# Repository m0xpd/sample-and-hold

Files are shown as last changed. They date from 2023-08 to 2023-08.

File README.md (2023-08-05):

# S&H
A Sample and Hold for Eurorack, based on the LF398

<p width=40%, align="center">

</p>  

This repository describes a simple sample & hold module, developed for electronic synthesisers, in Eurorack format, based on the
[LF398](https://www.ti.com/lit/gpn/lf398-n) device. 

**Functional Description**

S&H is designed to be a simple, "no frills" sample and hold. It just detects a rising edge on the TRIGGER input and samples the 
voltage applied to INPUT at the point of this edge and holds on OUTPUT until the next triggering event. There is a GATE output, 
which is asserted for as long as the TRIGGER signal is high and an internal clock, which generates a trigger stream normalled 
to the edge detection circuits when nothing else is plugged into the TRIGGER input.

**Licensing**

S&H is published under a Creative Commons BY-SA 4.0 [License](https://github.com/m0xpd/encore/blob/main/LICENSE.txt)

**Implementation**

The system is implemented on a single PCB.

The schematic for the system is linked by the graphic below below (click for the full-size schematic):

<p width=100%, align="center">

</p>  

**Specifications**

S&H is 6HP wide and extends 30mm behind the front panel (when a standard Eurorack power header is inserted).

S&H draws <9 mA (typically 5mA) from the +12V supply and <6 mA (typically 3mA) from the -12V supply.

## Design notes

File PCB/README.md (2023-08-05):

# PCB

This folder contains details of the PCB for the S&H module:

The PCB design files are presented in Eagle format.

Below you see a photo of the unpopulated PCB, top and bottom side

<p width=100%, align="center">

</p>  

## BoM and Capacitor Types

A Bill of Materials is available (in the verbose and not very useful style produced by Eagle.

The important things to note are that:
1) the jack sockets and the sample interval potentiometer are mechanically as well as electrically important; they 
control the spacing between the PCB and the front panel. For this reason, [Thonkiconn](https://www.thonk.co.uk/shop/thonkiconn/) sockets
and [alpha 9mm vertical potentiometers](https://www.thonk.co.uk/shop/alpha-9mm-pots-vertical-t18/) are specified.
2) Capacitor Types are as follows:
   C1 & C2 are polarised electrolytics

   C9 was chosen as a box polyester film (for space) - other types (such as multi-layer polyester) are suitable.
   
   C7 must be a low leakage type - I have used a box polyester film reasonably succesfully, but (e.g.) polystyrene would work better.
   
   ALL OTHER CAPS ARE CERAMICS

The populated PBC is seen from the component side in the photo below:

<p width=100%, align="center">

</p>

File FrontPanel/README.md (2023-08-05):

# Front Panel

This folder contains a simple Kicad project to create a front panel for the S&H module.

<p width=100%, align="center">

</p>  

The panel you see above was manufactured by [JLCPCB](https://jlcpcb.com/) (usual disclaimer) directly from the Gerbers generated by my design files.
It is aluminium and I specified black PCB, with white top screen (for the lettering). Other lines and annotation on the front 
are on the front mask layer.

There is a small text area on the bottom screen (the 'back' of the panel), which - importantly - includes a locator for the order 
number. Remember to select 'specify position' for the order number if you order from JLCPCB, otherwise they might place a meaningless 
number right over the front of your nice panel!

[JLCPCB](https://jlcpcb.com/) do a really good job of making the PCBs and (particularly) these front panels BUT there has been a >350% price increase on the panels since 
the last batches they made for me (for the [SubHarmonic Generator](https://github.com/m0xpd/SubHarmonics) and for the [Delay module](https://github.com/m0xpd/encore)). If you want pretty, black panels, I 
guess you have to pay.

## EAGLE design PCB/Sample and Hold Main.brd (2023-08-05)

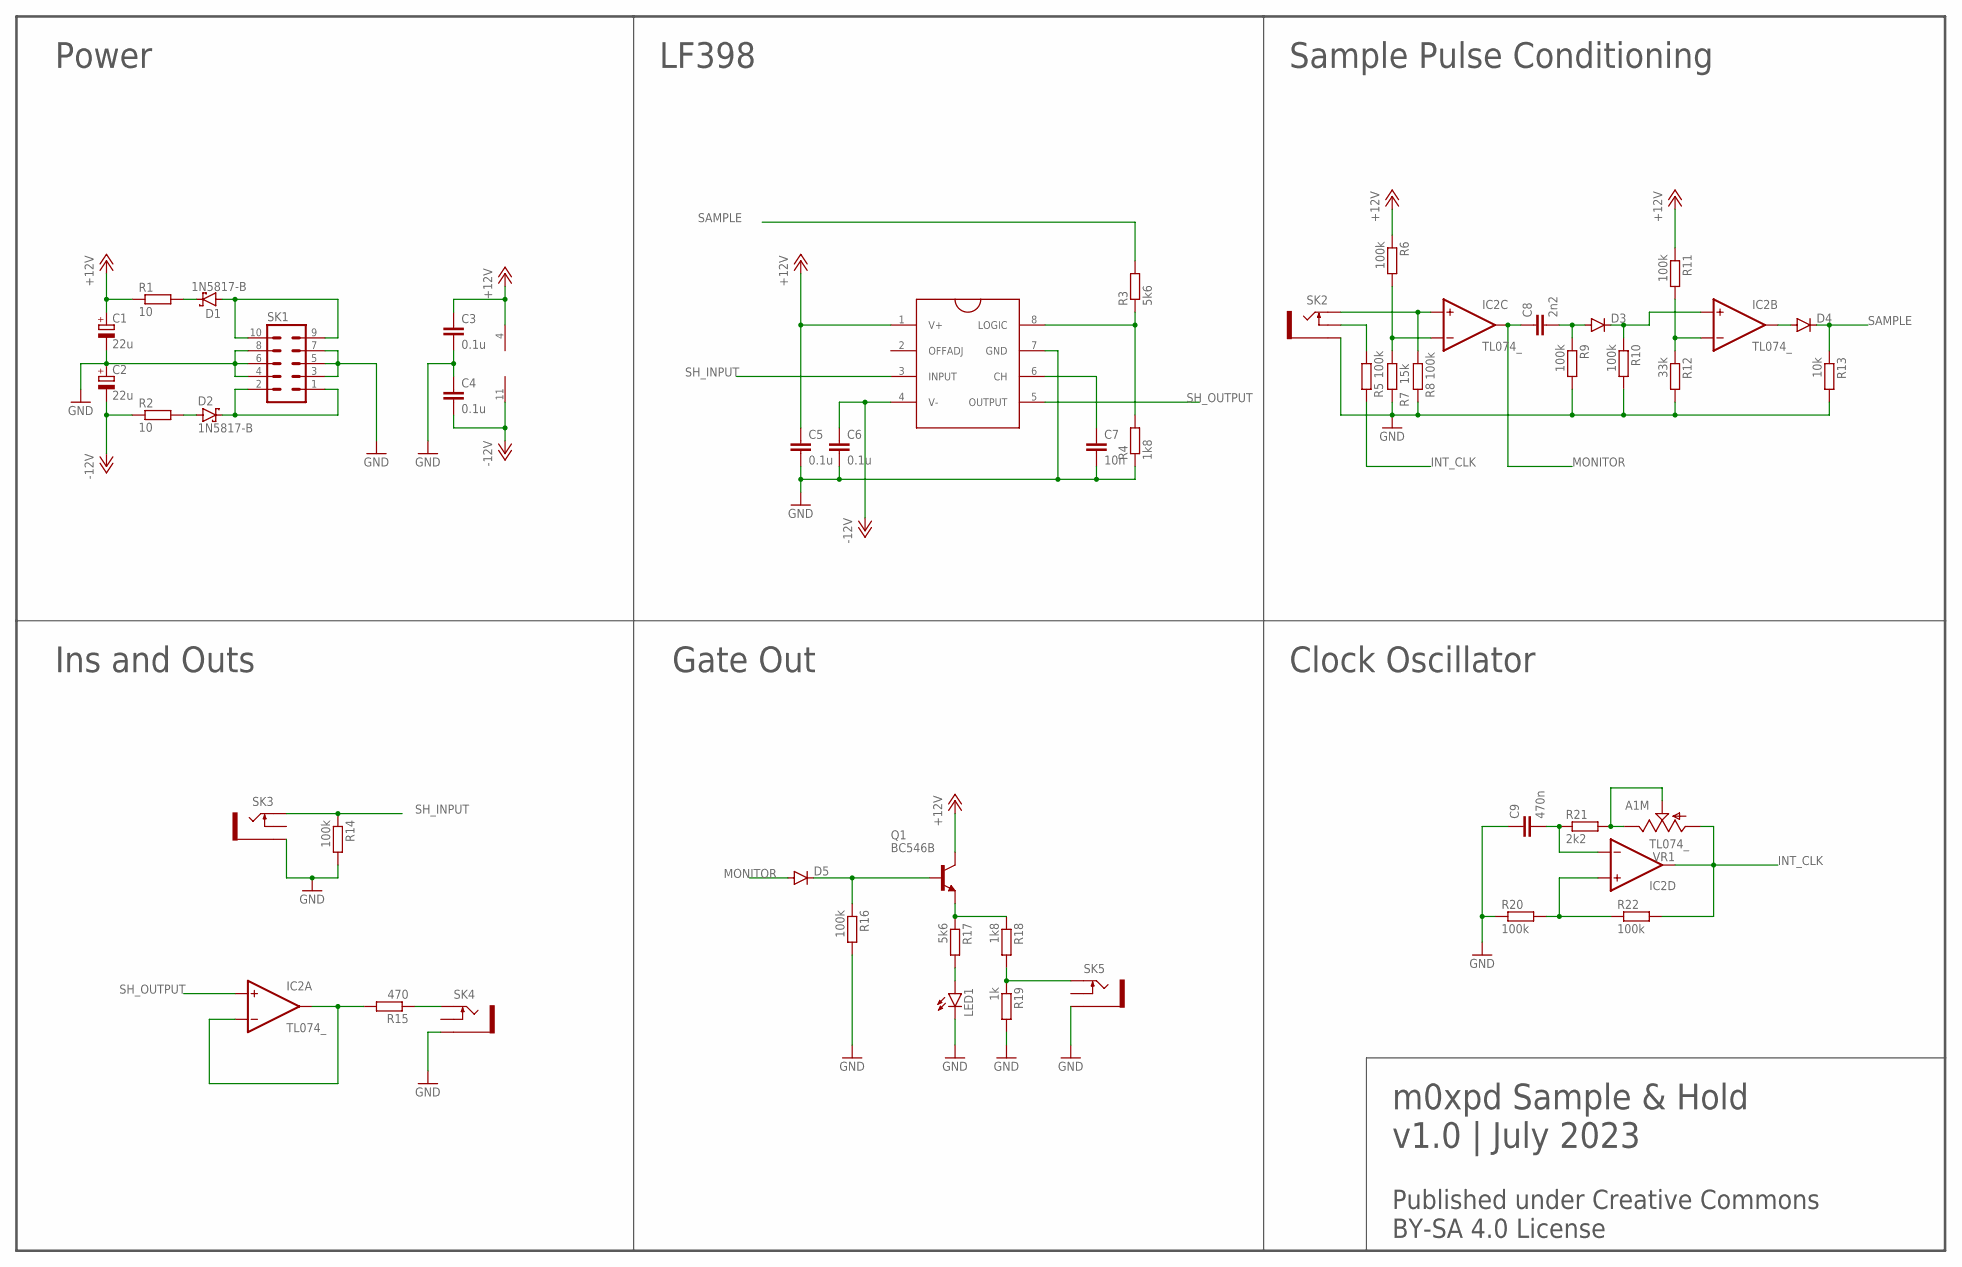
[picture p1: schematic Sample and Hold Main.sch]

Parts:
C1, C2: 22u; E2,5-6
C3, C4, C5, C6: 0.1u; C050-024X044
C7: 10n; C050-025X075
C8: 2n2; C050-024X044
C9: 470n; C050-035X075
D1, D2: 1N5817-B; DO41-7.6
D3, D4, D5: 1N4148DO35-7; DO35-7
IC1: LF398; DIL08
IC2: TL074_; DIL14
LED1: LED3MM
Q1: BC546B; TO92-EBC
R1, R2: 10; 0204/7
R3, R17: 5k6; 0204/7
R4, R18: 1k8; 0204/7
R5, R6, R8, R9, R10, R11, R14, R16, R20, R22: 100k; 0204/7
R7: 15k; 0204/7
R12: 33k; 0204/7
R13: 10k; 0204/7
R15: 470; 0204/7
R19: 1k; 0204/7
R21: 2k2; 0204/7
SK1: EURO_POWER_HEADERFAT_PADS; EURO_PWR_HEADER_FAT
SK2, SK3, SK4, SK5: THONKICONNNEW; WQP-PJ301M-12_JACK
VR1: A1M; 9MM_SNAP-IN_POT

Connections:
+12V: C1.+, C3.1, C5.1, IC1.1 (V+), IC2.4 (V+), Q1.C, R1.1, R6.1, R11.1
-12V: C2.-, C4.2, C6.1, IC1.4 (V-), IC2.11 (V-), R2.1
GND: C1.-, C2.+, C3.2, C4.1, C5.2, C6.2, C7.2, C9.1, IC1.7 (GND), LED1.K (C), R4.1, R7.2, R8.2, R9.2, R10.2, R12.2, R13.2, R14.2, R16.2, R19.2, R20.1, SK1.3, SK1.4, SK1.5, SK1.6, SK1.7, SK1.8, SK2.P$3_SLEEVE (SLEEVE), SK3.P$3_SLEEVE (SLEEVE), SK4.P$3_SLEEVE (SLEEVE), SK5.P$3_SLEEVE (SLEEVE)
INT_CLK: IC2.14 (OUT), R5.2, R22.2, VR1.1 (A)
MONITOR: C8.1, D5.A, IC2.8 (OUT)
unnamed: IC2.1 (OUT), IC2.2 (-IN), R15.2
unnamed: IC2.9 (-IN), R6.2, R7.1
unnamed: R15.1, SK4.P$1_TIP (TIP)
unnamed: C7.1, IC1.6 (CH)
unnamed: IC2.10 (+IN), R8.1, SK2.P$1_TIP (TIP)
unnamed: IC1.8 (LOGIC), R3.1, R4.2
unnamed: Q1.E, R17.1, R18.1
unnamed: C8.2, D3.A, R9.1
unnamed: D3.C, IC2.5 (+IN), R10.1
unnamed: LED1.A, R17.2
unnamed: IC2.6 (-IN), R11.2, R12.1
unnamed: D4.A, IC2.7 (OUT)
unnamed: C9.2, IC2.13 (-IN), R21.1
unnamed: IC2.12 (+IN), R20.2, R22.1
unnamed: D5.C, Q1.B, R16.1
unnamed: R21.2, VR1.2 (S), VR1.3 (E)
unnamed: R5.1, SK2.P$2_SWITCH (SWITCH)
unnamed: R18.2, R19.1, SK5.P$1_TIP (TIP)
unnamed: D2.C, SK1.1, SK1.2
unnamed: D1.A, SK1.9, SK1.10
unnamed: D1.C, R1.2
unnamed: D2.A, R2.2
SAMPLE: D4.C, R3.2, R13.1
SH_INPUT: IC1.3 (INPUT), R14.1, SK3.P$1_TIP (TIP)
SH_OUTPUT: IC1.5 (OUTPUT), IC2.3 (+IN)

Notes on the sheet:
Power
LF398
Sample Pulse Conditioning
Ins and Outs
Gate Out
Clock Oscillator
m0xpd Sample & Hold
v1.0 | July 2023
Published under Creative Commons BY-SA 4.0 License

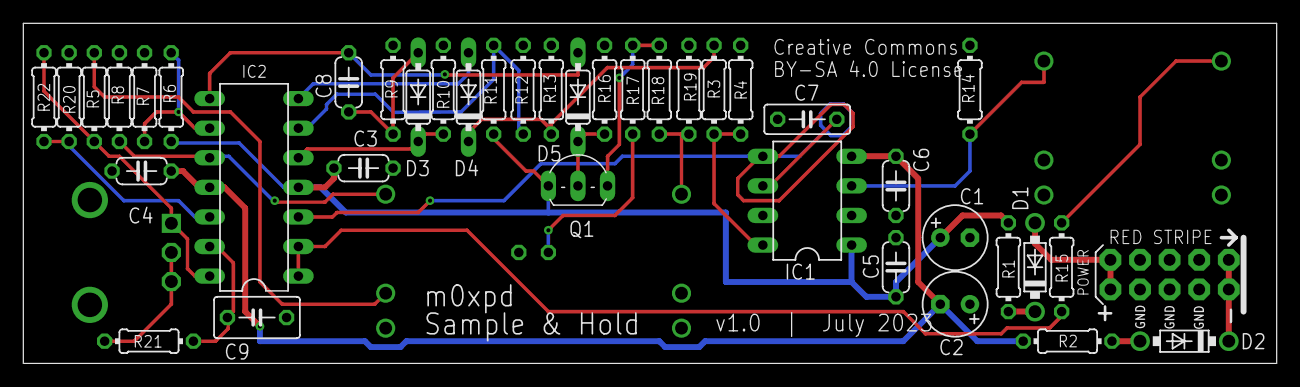
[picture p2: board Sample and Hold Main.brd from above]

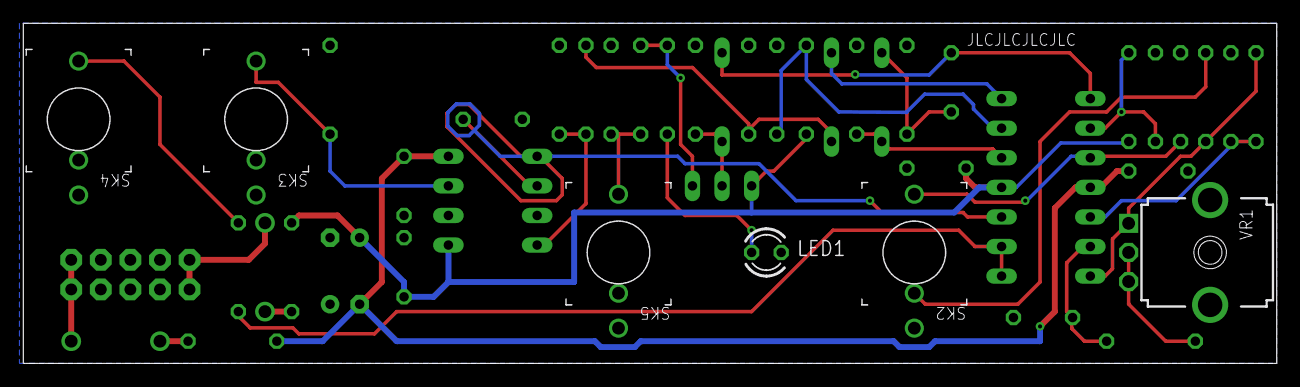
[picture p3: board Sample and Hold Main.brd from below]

Board: 2 copper layers, 107.6 x 29.2 mm, 46 parts (6 on the bottom side), 30 nets.

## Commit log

2023-08-05 Rename Sample and Hold BoM.txt to PCB/Sample and Hold BoM.txt
2023-08-05 Rename Sample and Hold Main.brd to PCB/Sample and Hold Main.brd
    [Sample and Hold Main.brd]
2023-08-05 Rename Sample and Hold Main.sch to PCB/Sample and Hold Main.sch
    [Sample and Hold Main.sch]
2023-08-05 Rename Sample & Hold.kicad_pcb to FrontPanel/Sample & Hold.kicad_pcb
    [Sample & Hold.kicad_pcb]
2023-08-05 Rename Sample & Hold.kicad_pro to FrontPanel/Sample & Hold.kicad_pro
2023-08-05 Rename Sample & Hold.kicad_sch to FrontPanel/Sample & Hold.kicad_sch
    [Sample & Hold.kicad_sch]
